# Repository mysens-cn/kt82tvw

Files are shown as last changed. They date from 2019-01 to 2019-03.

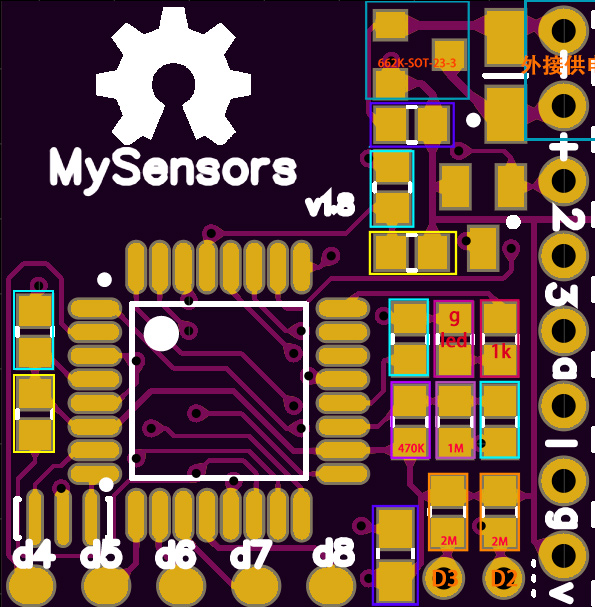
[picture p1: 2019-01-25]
doc/MINI.jpg

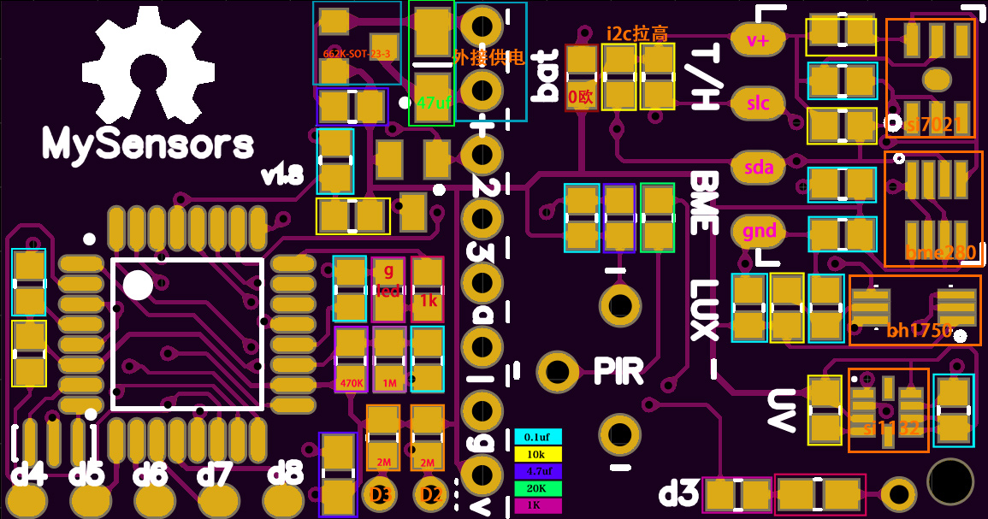
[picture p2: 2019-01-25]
doc/package.jpg

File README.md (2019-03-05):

# MYNRF24
mysensor nrf24 with battery cr2032/cr2450 

```
1.门磁功耗： 未触发3ua，触发极值15ma,未有未波器，时间未知，按其它资料单次消耗应该小于500ms

2.继电器操作完好，已知问题如下：HA批量操作没有延时，模块为半双工，大量操作会造成网关瞬间发送
无法接收节点发回ACK，导致状态不对，目前我还在集测中;由于使用非原装挪威产芯片，国产或者山寨丢
包率远超原装水平，也不排除这个原因！

3.I2C由于不同的芯片，对电压要求较高，特别是BH1750，另外CR2032极限电流输出在15ma会产生大量压
降导致电池无法完全使用完，200mah可能只能使用掉150？未知，目前靠代码能轻微解决

```
目前BH1750,si7021工作1月27日上电，到目前未止，万用表实测2.9V，工作压降到2.5V，门磁电压与上电一致，波动小于0.2v无法上报

## QQ讨论群

mynrf24-front

PCB尺寸 : 39.12mmX20.57mm 支持沿虚线切割，切割后使用尺寸20.57mmmX20.06mm

## PIC
### Front pic

mynrf24-front

### Back pic

mynrf24-front

### package 

package

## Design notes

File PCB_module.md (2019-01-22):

MYNRF24PCB贴片说明和细节

　　MYNRF24-CR2032板涉及元件比较多，兼容了比较多的可能性，故开贴一一说明，方便大家理解需要核贴的元器件.

##整板介绍
PCB尺寸 : 39.12mmX20.57mm 支持沿虚线切割，切割后使用尺寸20.57mmmX20.06mm

### Front pic
mynrf24-front

### Back pic
mynrf24-front
### package 

package
　　此图为整板元件介绍，D2 D3为mcu处理单元的物理中断脚，模块支持外接供电，沿线切割使用，支持固有标准模块，比如gy-302(bh1750)、si7021迷你、支持bme280等，查看时候请使另存或者使用浏览器插件放大！PIR-AM312上元件的时候请务必不要贴板，合理避开元件，建议上高2-3mm左右

##模块选择

### 基础原板


####0.1uf电容3颗，10K电阻两颗，4.7uf或者47uf电容(0603/0805)一颗



### 二进制传感器


####D2、D3均为支持门磁、雨滴、无线按键等，使用时请上拉1M或者2M电阻，电耗上1M>2M,

### I2C传感器


####按图区域，使用时对应帖电阻电容，如果出现I2C掉压，请使用bat右边2个贴脚上拉slc和sda

### MINI模块


####按板上虚线位置，使用美工刀划开，双面达到一定深度，使用工具掰开即可。

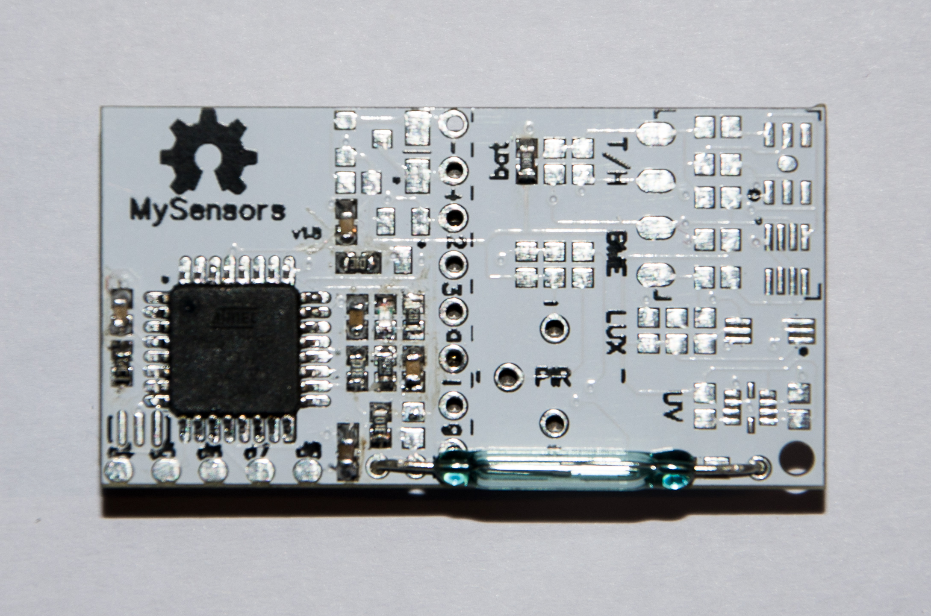
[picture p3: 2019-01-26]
doc/package/DOOR.jpg

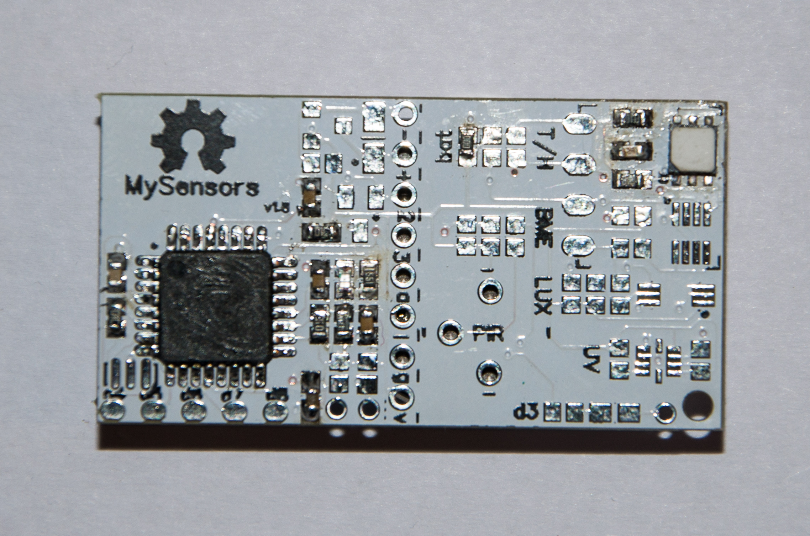
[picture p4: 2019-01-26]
doc/package/SI7021.jpg

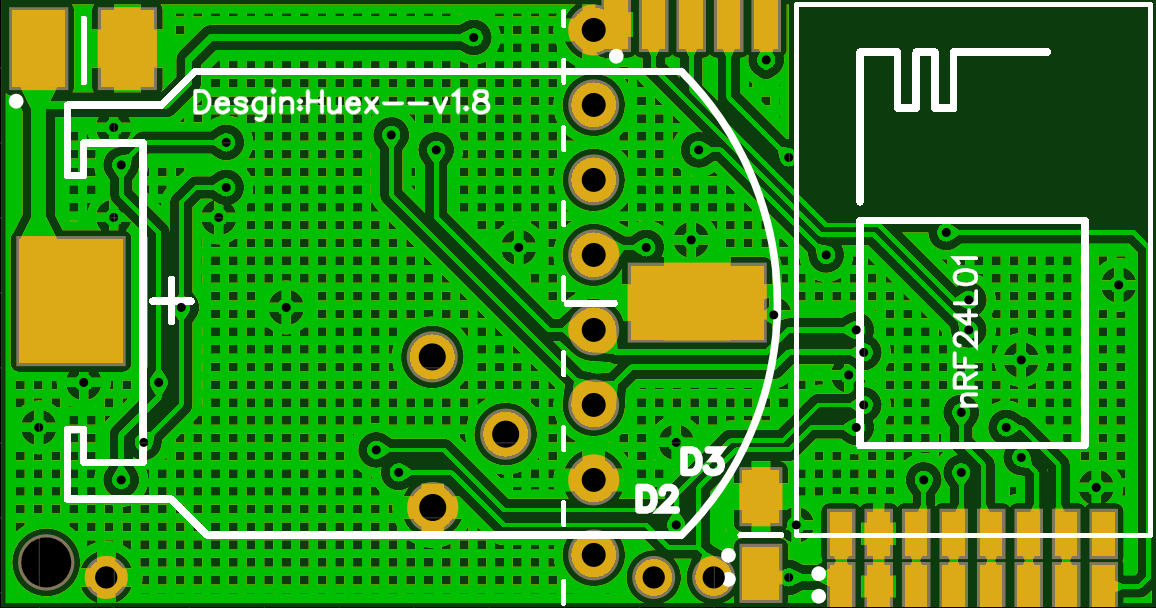
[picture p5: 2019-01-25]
doc/back.png

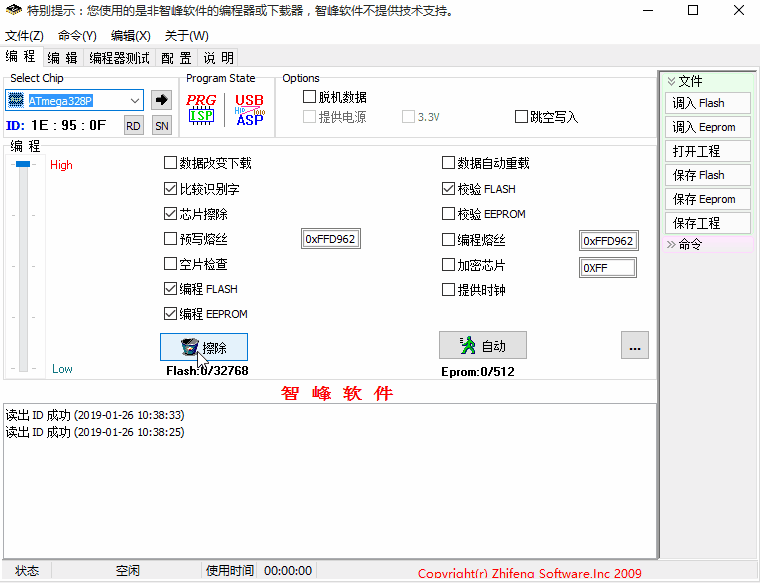
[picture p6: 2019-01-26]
doc/proisp-flash.gif

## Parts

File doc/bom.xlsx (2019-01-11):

ID | 名称 | 电容脚位名 | 封脚 | 数量 | 淘宝型号 | 必要性
1 | MEGA328P-AU | IC1 | 328P-AU | 1 | atmega328p-au | 是
2 | 100nf-0603-x7r | C2,C1,C5,C7,C10,C8,C11,C12,C4,C16,C17 | 0603 | 11 | 100nf(0.1uf) 0603 x7r (https://s.taobao.com/search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) | 是
3 | SI7021 | IC3 | SI7021-DFN | 1 | SI7021-A20-GM1R (https://s.taobao.com/search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) | 非
4 | 10K 0603±5% | R1,R2,R3,R6,R9,R12,R5,R17 | 0603 | 8 | 10K 0603±5% | 是
5 | 1M | R7 | 0603 | 1 | 1M 0603±5% | 是
6 | 470k | R8 | 0603 | 1 | 470K 0603±5% | 是
7 | ATSHA204A | IC4 | SOT23-3-L | 1 | ATSHA204A SOT-23 | 非
8 | NRF24L01_SMD | U1 | NRF24L01 | 1 | NRF24L01无线迷你 (https://item.taobao.com/item.htm?spm=a230r.1.14.97.19573b62H8tdap&id=40352572949&ns=1&abbucket=11) | 是
9 | SI7021-SMD | U2 | SI7021-SMDM | 1 | 成品模块参考图 | 非
10 | 2.54-8P | U9 | 2.54-8P | 1 | 2.54直针 | 非
11 | 1.27-SMD-5P | U11 | 1.27-5P | 1 | 1.27 for 5p ttl | 非
12 | 1k | R4,R15,R16,R18 | 0603 | 4 | 1K 0603 ±5% (https://s.taobao.com/search?q=1K+0603+±5%25&imgfile=&js=1&stats_click=search_radio_all%3A1&initiative_id=staobaoz_20190111) | 非
13 | LED | LED | 0603 | 1 | 0603 LED | 非
14 | si1132 | U5 | SI1132 | 1 | Si1132-A10-GMR | 非
15 | BS-8-1 | B1 | BATTERY-5 | 1 | BS-8 CR2032 (https://s.taobao.com/search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) | 非?
16 | 0欧 | R14 | 0603 | 1 | 0欧 0603 | 非
17 | xc6206p332mr | IC2 | SOT-23-3 | 1 | 662k sot-23 | 非?
18 | 4.7uF | C14,C6,C3,C13 | 0603 | 2 | 0603 4.7uf x7r (https://s.taobao.com/search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) | 是？
19 | 47uF | C9 | 3216 | 1 | 钽电容 47UF 3216 | 非
20 | 100uf | C9 | 3216 | 1 | 钽电容 100UF 3216 | 非
21 | bh1750 | U7 | BH1750FVI-L | 1 | BH1750FVI-TR (https://s.taobao.com/search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) | 非
22 | BME280 | U12 | BME280 LGA | 1 | BME280 LGA | 非
23 | CSTCE16M0V53 | X2 | CSCTE16 | 1 | CSTCE16 3脚 | 非
24 | AS312 | CGQ2 | AS312T | 1 | AS312/am312 人体感应热释探头 | 非
25 | 20K | R13 | 0603 | 1 | 20KΩ ±1% 0603 | 非
26 | 220uF | C15 | 3528 | 1 | 3528钽电容 220uf | 非
27 | 2M | R5,R17 | 603 | 2 | 2M 0603±5% | 非
说明： | 核心328p完整需要4个0.1uf电容，2个10K电阻
 | 电池电量读取需要0.1uf电容+1M电阻+470k电阻
 | nrf24l01至少需要使用4.7uf电容，备47uf电容（0603或者0805都可）或者备3216钽电容(47uf或者100uf )
 | 人体感应需要提供20k电阻和0.1uf 电容和 4.7uf电容
 | si7021、bh1750fvi、si1132、bme280等均需要增加0.1uf电容和10k电阻，数量2-3不等
 | x2脚位为晶振脚，非必要，可备1颗，
 | 列表中100uf电容和220uf电容仅为改善电池压降，目前测试效果不明显，自行斟酌是否需要，非必要
 | 需要使用执行继电器等有外接电源使用的，请购买662k模块，支持最高6.3V输入，需要4.7uf（0603或0805）和47uf电容(可选0805 3216钽电容)
支持以下成品模块
 |  | GY-302 BH1750 | BME280 |  | SI7021
 | 接口顺序为 | VCC-GND-SLC-SDA 2.54mm间距均可，最好背面无电容
刷机工具
 | 板带1.27mm接口标准，支持usbasp和ttl两组，建议使用1.27 sop16夹烧录夹
 | sop16烧录夹 | usbasp下载器avr ，确定是usbasp即可，无需与图一致，此工具为写bootloader工具 |  |  | usb cp2102 ttl，确保有DTR接口
对于烧录夹，购买单夹后可以配合这个链接的转接板.1.27mm sop16，然后切开焊接使用
 |  | 链接， (https://detail.tmall.com/item.htm?id=570010334729&ns=1&abbucket=11&skuId=3832903578534)
直接焊接线也是可行的。
网关请购买一片
NRF24L01+8P

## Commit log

2019-01-11 frist
    add pic and boom
    [bom.xlsx]
2019-01-11 switch
    switch to doc
    [bom.xlsx]
2019-01-11 update 2MOM
    add 2Mohm
    [bom.xlsx]
2019-01-11 添加网关芯片
    [bom.xlsx]
2019-01-11 增加模块化图片
2019-01-11 更新DOC
2019-01-11 模块化说明
2019-01-22 add gateway bin file
    /斜眼笑QNAP，笑不语
2019-01-25 add i2c brinary
2019-03-05 添加制造文件
    添加制造文件
    [Gerber_BoardOutline.GKO, Gerber_BottomLayer.GBL, Gerber_BottomPasteMaskLayer.GBP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]
2019-03-05 更新相关说明
